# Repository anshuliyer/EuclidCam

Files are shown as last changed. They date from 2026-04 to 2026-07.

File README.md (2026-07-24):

# EuclidCam

Custom embedded camera firmware for a Raspberry Pi point-and-shoot. Runs headlessly on a 480×320 SPI display with a capacitive touch panel.

```
euclidcam/
├── firmware/python/       # On-device firmware runtime engine
│   ├── main.py            # Main entry point and orchestration loop
│   ├── filters/           # Custom PIL photo filters (Glam, 35mm, Summer, etc.)
│   ├── UI/                # Display renderer, touch digitizer driver, and themes
│   ├── settings/          # Viewfinder composition grids (3x3, Golden Ratio)
│   ├── connectivity/      # Flask remote control server & Wi-Fi configuration
│   └── IO/                # Hardware GPIO flash & battery management
├── docs/                  # Technical documentation & hardware reference manual
├── scripts/               # Bootstrapping & asset utility scripts
├── assets/                # Core visual media, logos, and typography fonts
├── tests/                 # Firmware test suite
├── Makefile               # Installation, deployment, and service targets
├── requirements.txt       # Python dependencies
└── LICENSE                # GNU Affero General Public License v3.0 (AGPLv3)
```

*(Note: The `Captured/` photo directory is automatically created dynamically on first start by the firmware engine).*

## Setup

This software is production-ready and shippable. Hardware dependencies (`picamera2`) are assumed to be available via the Raspberry Pi OS `apt` repositories. Python dependencies are strictly pinned.

```bash
make install          # installs apt dependencies and pip requirements.txt
make run              # foreground launch
make service-install  # register systemd unit
```

## Dev

```bash
make check   # syntax-check all .py files
make lint    # flake8
make clean   # remove __pycache__, temp.jpg
```

## License
This project is licensed under the **GNU Affero General Public License v3.0 (AGPLv3)** — see the [LICENSE](LICENSE) file for details.

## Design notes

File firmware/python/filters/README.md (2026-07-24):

# filters/

Each file exposes one function: `apply_<name>_filter(pil_img) -> Image`.  
`FilterMode` in `main.py` discovers it automatically by name convention.

| Module | Name | Look |
|---|---|---|
| `glam.py` | Glam | High-contrast B&W, soft gaussian glow |
| `nineties.py` | '90s | Lifted matte blacks, punchy contrast, 90s print|
| `film35mm.py` | 35mm | Point-and-shoot flash, lifted blue shadows |
| `indoor.py` | Indoor | Warm shadows, low contrast, indoor flash feel |
| `italian_summer.py` | Summer | Vivid Mediterranean warmth |
| `uni.py` | UnI | Vintage warm tint, lifted shadows |
| `nostalgia.py` | Nostalgia | Faded, desaturated retro |
| `low_light.py` | — | Used by `LowLightMode`, not in filter menu |

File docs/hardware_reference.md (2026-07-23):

# EuclidCam Core Reference
This document outlines the core dependencies, execution commands, and hardware initialization steps for the EuclidCam firmware. You can use this as a reference for integrating the camera engine and touch UI into other SDK projects.

## Fresh OS Setup (From Scratch)

If you are starting from a completely blank, freshly flashed Raspberry Pi OS memory card, run these exact shell commands in order over SSH or a connected keyboard:

```bash
# 1. Update the system package lists
sudo apt-get update -y
sudo apt-get upgrade -y

# 2. Enable SPI and I2C interfaces (Required for Display and Hardware Sensors)
sudo raspi-config nonint do_spi 0
sudo raspi-config nonint do_i2c 0

# 3. Clone the EuclidCam repository
git clone https://github.com/anshuliyer/EuclidCam.git
cd EuclidCam

# 4. Install all hardware and python dependencies via the Makefile
make install

# 5. Enable the EuclidCam systemd service to start automatically on boot
make service-install

# 6. Reboot the system to apply SPI/I2C changes and start the camera!
sudo reboot
```

## Hardware Wiring Guide

To ensure the firmware seamlessly communicates with the hardware, follow this pinout configuration.

### 1. ILI9341 Display (SPI)
- **MOSI / MISO / SCLK:** Standard Raspberry Pi SPI0 pins (GPIO 10, 9, 11)
- **CS (Chip Select):** GPIO 8 (CE0)
- **DC (Data/Command):** GPIO 24
- **RST (Reset):** GPIO 25
- **BL (Backlight):** Connect to 3.3V or 5V (depending on your module)

### 2. XPT2046 Touch Digitizer (SPI)
The touch controller shares the same SPI bus as the display, but uses a different Chip Select pin.
- **MOSI / MISO / SCLK:** Share with the Display
- **CS (Chip Select):** GPIO 7 (CE1)
- **IRQ (Pen Interrupt):** GPIO 17

### 3. Physical Shutter Button
- Wire a tactile button between **GPIO 21** and **GND**. The firmware uses an internal pull-up resistor, so it reads active-low when pressed.

### 4. Camera Module
- Connect a compatible camera module (e.g., Raspberry Pi Camera V2 or HQ Camera) via the CSI ribbon cable port. The libcamera backend will automatically detect the sensor type upon boot.
## Core Dependencies

To run the camera engine, display, and touch drivers, the following dependencies are required.

### 1. System Packages (APT)
On a Raspberry Pi, it is heavily recommended to install the hardware-linked Python packages via `apt` to avoid complex wheel compilation for the ARM architecture (especially for `numpy` and `picamera2`).
```bash
sudo apt-get update
sudo apt-get install -y python3-picamera2 python3-numpy python3-pil python3-flask python3-evdev python3-qrcode python3-requests python3-adafruit-blinka python3-adafruit-circuitpython-rgb-display libcap-dev libcamera-apps
```

### 2. Python Packages (PIP)
If you are setting up an isolated virtual environment, you can use `pip`:
```text
Pillow>=9.0.0
numpy>=1.21.0
Flask>=2.0.0
qrcode>=7.0
adafruit-circuitpython-rgb-display>=3.0.0
Adafruit-Blinka>=8.0.0
evdev>=1.6.0
```

---

## Execution Commands

### Running the Camera (Standard Mode)
Boots the camera engine, rendering the UI and camera feed directly to the ILI9341 SPI display.
```bash
# Using the Makefile wrapper:
make run

# Running directly from the Python layer:
cd firmware/python
python3 main.py
```

### Running the Camera (Benchmark Mode)
Boots the camera engine while drawing a live uptime timer to the screen. It also spawns a background daemon thread that queries the Raspberry Pi's `vcgencmd get_throttled` state every 60 seconds and logs the results to a local CSV file to test battery life.
```bash
# Using the Makefile wrapper:
make benchmark

# Running directly from the Python layer:
cd firmware/python
python3 main.py --benchmark
```

---

## Touch Screen Integration

The touch interface utilizes the resistive touchscreen digitizer (typically an XPT2046 or ADS7846) over SPI. 

### 1. Touch digitizer logic
Because the graphical UI (Pillow) and the hardware display (`ili9341`) handle rotations differently, the raw coordinates from the touch digitizer must be mapped to the actual screen geometry.

**Hardware Driver:** `evdev` is used to capture `ABS_X` and `ABS_Y` touch events in `calibrate_touch.py`.
**Firmware Parsing:** In `touch_interface.py`, the firmware directly speaks to the SPI hardware bus at `1MHz` to bypass OS-level touch noise and read stable ADC voltages.

### 2. Touch Calibration
Before the UI can accurately determine button presses, the raw touch digitizer bounds must be mapped. 
Run the following interactive calibration script and tap the four corners of the screen when prompted:
```bash
cd firmware/python
python3 calibrate_touch.py
```
This generates a `touch_settings.json` file containing the `x_min`, `x_max`, `y_min`, and `y_max` mappings used by the UI engine.

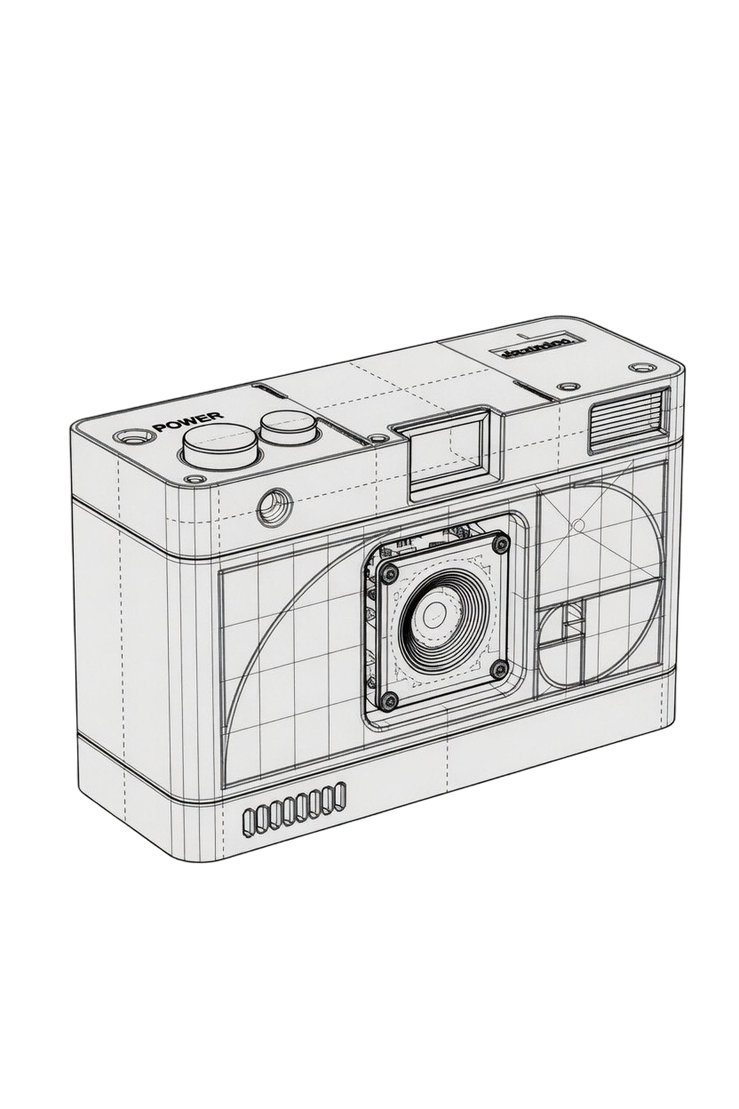
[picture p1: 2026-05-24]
assets/camera_blueprint.png

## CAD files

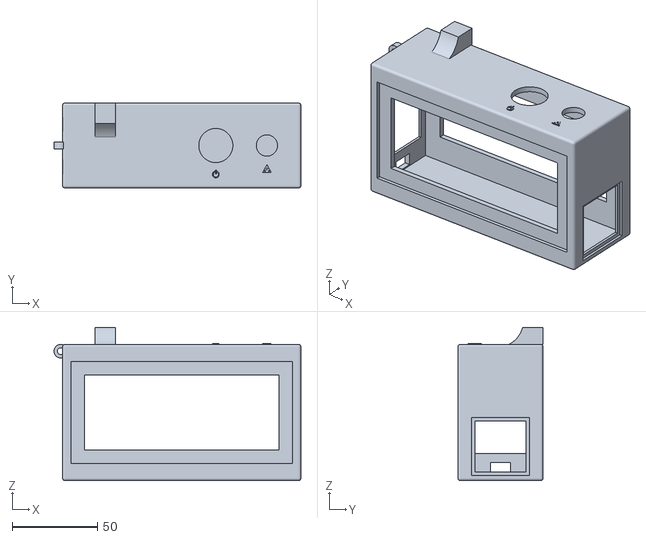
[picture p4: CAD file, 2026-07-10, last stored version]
Webapp/exports/main_chassis.stl
145.0 x 50.0 x 90.0

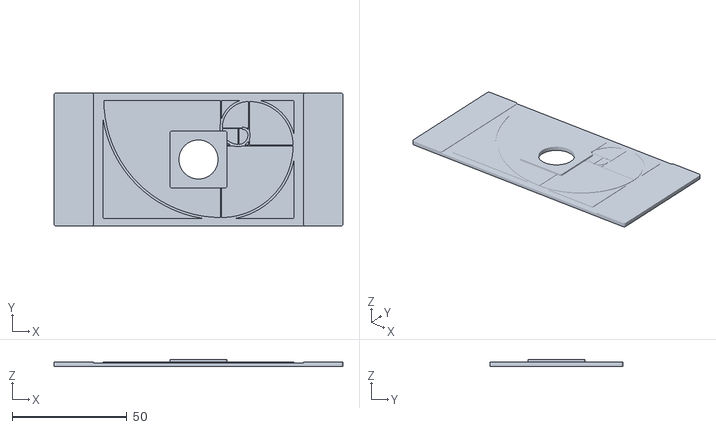
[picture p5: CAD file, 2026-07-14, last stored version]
Webapp/exports/front_plate.stl
126.0 x 58.0 x 3.00

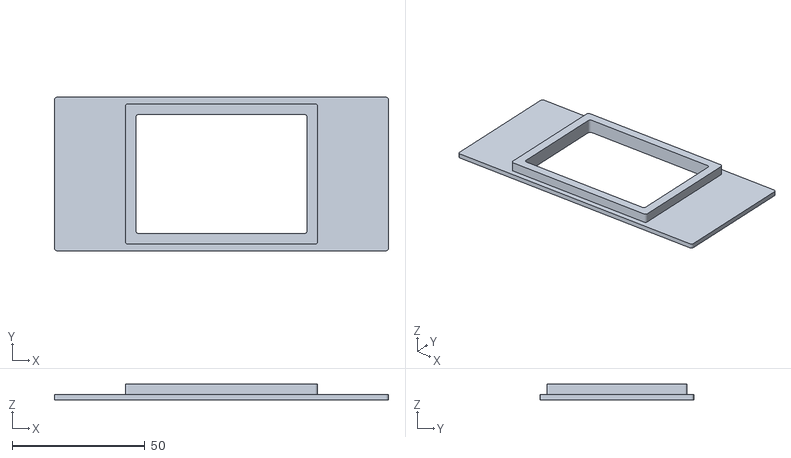
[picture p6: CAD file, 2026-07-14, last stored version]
Webapp/exports/back_plate.stl
126.0 x 58.0 x 6.00

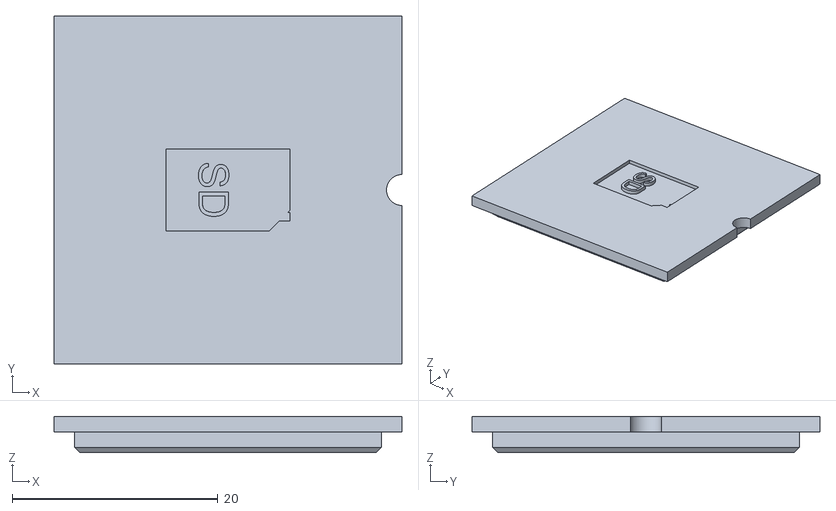
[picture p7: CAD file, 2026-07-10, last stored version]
Webapp/exports/sd_door.stl
33.8 x 33.8 x 3.50

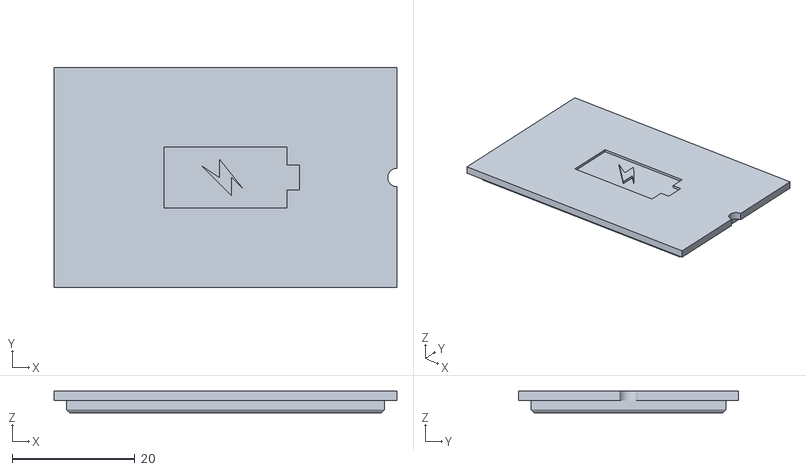
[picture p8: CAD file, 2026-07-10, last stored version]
Webapp/exports/battery_door.stl
55.8 x 35.8 x 3.50

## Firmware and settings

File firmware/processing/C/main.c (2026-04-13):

#define STB_IMAGE_IMPLEMENTATION
#include "stb_image.h"
#define STB_IMAGE_WRITE_IMPLEMENTATION
#include "stb_image_write.h"

#include <stdio.h>
#include <stdlib.h>

/**
 * PiDigiCam: Minimal C Image Enhancer for ARMv6
 * 
 * This entry point is designed for debian-based ARMv6 microcontrollers.
 * It uses the 'stb' single-header libraries for zero-dependency image I/O.
 */

// Simple Bilinear Upscaling (Baseline Enhancement)
void upscale_x2(unsigned char* src, int sw, int sh, unsigned char* dst) {
    int dw = sw * 2;
    int dh = sh * 2;
    for (int y = 0; y < dh; y++) {
        for (int x = 0; x < dw; x++) {
            float gx = (float)x / 2.0f;
            float gy = (float)y / 2.0f;
            int gxi = (int)gx;
            int gyi = (int)gy;
            
            // Simple nearest/bilinear mix for performance on ARMv6
            dst[y * dw + x] = src[gyi * sw + gxi];
        }
    }
}

int main(int argc, char** argv) {
    if (argc < 3) {
        fprintf(stderr, "Usage: %s <input.jpg> <output.png>\n", argv[0]);
        return 1;
    }

    const char* input_path = argv[1];
    const char* output_path = argv[2];

    int width, height, channels;
    printf("Loading image: %s\n", input_path);
    unsigned char* img = stbi_load(input_path, &width, &height, &channels, 0);
    
    if (!img) {
        fprintf(stderr, "Error: Could not load image %s\n", input_path);
        return 1;
    }

    printf("Image Loaded: %dx%d, %d channels\n", width, height, channels);
    
    int out_w = width * 2;
    int out_h = height * 2;
    unsigned char* out_img = (unsigned char*)malloc(out_w * out_h * channels);

    if (!out_img) {
        fprintf(stderr, "Error: Out of memory\n");
        stbi_image_free(img);
        return 1;
    }

    printf("Enhancing image to %dx%d...\n", out_w, out_h);
    
    // Process each channel
    for (int c = 0; c < channels; c++) {
        unsigned char* src_c = (unsigned char*)malloc(width * height);
        unsigned char* dst_c = (unsigned char*)malloc(out_w * out_h);
        
        // Extract channel
        for (int i = 0; i < width * height; i++) src_c[i] = img[i * channels + c];
        
        upscale_x2(src_c, width, height, dst_c);
        
        // Insert channel back
        for (int i = 0; i < out_w * out_h; i++) out_img[i * channels + c] = dst_c[i];
        
        free(src_c);
        free(dst_c);
    }

    printf("Writing output: %s\n", output_path);
    if (!stbi_write_png(output_path, out_w, out_h, channels, out_img, out_w * channels)) {
        fprintf(stderr, "Error: Could not save image %s\n", output_path);
    } else {
        printf("Successfully enhanced image!\n");
    }

    stbi_image_free(img);
    free(out_img);

    return 0;
}

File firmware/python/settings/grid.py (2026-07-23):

import numpy as np
from PIL import Image, ImageDraw

class CompositionGrid:
    """
    Handles drawing compositional grids (3x3, Golden Ratio/Euclid) on PIL images.
    """
    OFF = "OFF"
    GRID_3x3 = "3x3"
    EUCLID = "Euclid"

    def __init__(self, color=(220, 220, 200), width=2):
        self.color = color
        self.width = width

    def apply(self, pil_img, mode):
        """
        Applies the selected grid mode to the PIL image.
        """
        if mode == self.OFF or not mode:
            return pil_img
        
        draw = ImageDraw.Draw(pil_img)
        w, h = pil_img.size

        if mode == self.GRID_3x3:
            # Rule of Thirds
            # Vertical
            draw.line([(w // 3, 0), (w // 3, h)], fill=self.color, width=self.width)
            draw.line([(2 * w // 3, 0), (2 * w // 3, h)], fill=self.color, width=self.width)
            # Horizontal
            draw.line([(0, h // 3), (w, h // 3)], fill=self.color, width=self.width)
            draw.line([(0, 2 * h // 3), (w, 2 * h // 3)], fill=self.color, width=self.width)
        
        elif mode == self.EUCLID:
            # True Golden Spiral (Fibonacci recursive squares and arcs)
            phi = 1.61803398875
            
            # Center a perfect Golden Rectangle in the screen
            if w / h > phi:
                # Screen is wider than GR, center horizontally
                gr_h = h
                gr_w = int(h * phi)
                x0 = (w - gr_w) // 2
                y0 = 0
            else:
                # Screen is taller than GR, center vertically
                gr_w = w
                gr_h = int(w / phi)
                x0 = 0
                y0 = (h - gr_h) // 2

            rx, ry, rw, rh = x0, y0, gr_w, gr_h
            
            # Direction of the cut: 0: right, 1: top, 2: left, 3: bottom
            direction = 0
            for i in range(8): # 8 iterations is visually perfect
                if rw < 2 or rh < 2: break
                
                sq = min(rw, rh)
                
                if direction == 0: # Right
                    sx, sy = rx + rw - sq, ry
                    rw -= sq
                    cx, cy = sx, sy + sq
                    start, end = 270, 360
                elif direction == 1: # Top
                    sx, sy = rx, ry
                    ry += sq
                    rh -= sq
                    cx, cy = sx + sq, sy + sq
                    start, end = 180, 270
                elif direction == 2: # Left
                    sx, sy = rx, ry
                    rx += sq
                    rw -= sq
                    cx, cy = sx + sq, sy
                    start, end = 90, 180
                else: # Bottom
                    sx, sy = rx, ry + rh - sq
                    rh -= sq
                    cx, cy = sx, sy
                    start, end = 0, 90
                    
                # Draw the bounding square
                draw.rectangle([sx, sy, sx + sq, sy + sq], outline=self.color, width=self.width)
                
                # Draw the golden arc
                draw.arc([cx - sq, cy - sq, cx + sq, cy + sq], start, end, fill=self.color, width=max(1, self.width))
                
                direction = (direction + 1) % 4
                
        return pil_img

if __name__ == "__main__":
    # Simple standalone verification (Mocks FB/Camera if needed, but here just testing PIL)
    print("CompositionGrid Class test...")
    test_img = Image.new('RGB', (480, 320), color=(255, 255, 255))
    grid = CompositionGrid()
    
    # Test Euclid
    res = grid.apply(test_img.copy(), CompositionGrid.EUCLID)
    res.save("test_euclid.png")
    print("Saved test_euclid.png")
    
    # Test 3x3
    res = grid.apply(test_img.copy(), CompositionGrid.GRID_3x3)
    res.save("test_3x3.png")
    print("Saved test_3x3.png")

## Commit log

2026-04-13 [PCD] kodak 35mm filter added
2026-04-14 [prebuilts] Update enhance prebuilt for Raspberry Pi Zero W (ARMv6)
2026-04-23 [ECD] Placing mounted system
2026-04-23 [ECD] Filter interfaces
2026-04-23 Cross button
2026-04-23 [FIX] obsolete qr_scanner import
    [main.py]
2026-04-23 added device storage status to web ui
2026-04-25 [TOUCH] Fixed axis swapping logic in touch interface
    [touch_interface.py]
2026-04-25 [ECD] Replaced vertical list menu with a robust horizontal grid layout for better touch performance
    [touch_interface.py]
2026-04-25 [ECD] Optimization: Increased FPS and tuned camera clarity/contrast
2026-04-26 Revert "[ECD] Optimization: Optimized framebuffer write speed to reduce tearing"
    This reverts commit c0d1807daac61a9c9b0022805cc1ead2708e2685.
    [main.py]
2026-04-26 Revert "[ECD] Optimization: Increased FPS and tuned camera clarity/contrast"
    This reverts commit f297dd2e82d9a20c8d9719d5d314c7c6518bad98.
    [main.py]
2026-04-26 [ECD] Added dedicated Low Light mode with hardware noise reduction and preview boosting
    [main.py, touch_interface.py]
2026-04-26 [ECD] Modularized Low Light logic into filters directory
2026-04-26 [ECD] Improved touch isolation by increasing button margins and reducing impact area
2026-04-26 [ECD] Premium UI Redesign: Implemented card-based grid with custom iconography and glassmorphism
    [touch_interface.py]
2026-04-26 [ECD] Refactored touch logic to Layered Mapping system: fixed corner selection bug
    [touch_interface.py]
2026-04-26 [ECD] Redesigned capture logo to use geometric triangle (removed cross look)
    [main.py]
2026-04-26 [ECD] UI Refactor: Translucent glass buttons in settings menu & expanded QR close hitbox
2026-04-26 [ECD] Made QR close button visually massive and easily tappable
2026-04-26 [ECD] Standardized massive cross button across all menus & fixed QR code touch fallthrough bug
    [touch_interface.py]
2026-04-26 [ECD] Replaced Cyberpunk filter with UnI vintage film aesthetic
    [main.py, uni.py]
2026-04-26 [ECD] Replaced Kodak filter with gritty 35mm point-and-shoot flash aesthetic
    [film35mm.py, main.py]
2026-04-26 [ECD] Forced camera capture to match preview FOV by using 1080p cropped sensor mode
2026-04-26 [ECD] Replaced Bokeh filter with Indoor filter (warm, lifted shadows aesthetic)
    [indoor.py, main.py]
2026-04-26 [ECD] Reverted hardware zoom config; implemented slight 1.05x digital crop for saving
    [main.py]
2026-04-26 [ECD] Updated zoom to 1.6x (Standard lens equivalent) and unified preview/capture cropping
2026-04-26 [ECD] Fixed gallery access: added missing GALLERY command handler to InputHandler
    [main.py]
2026-04-26 [ECD] Re-styled Gallery UI to match Settings: unified header, glassmorphism cards, and standard cross button
2026-04-27 [UI] Implement 180-degree orientation flip and settings persistence
    [main.py, touch_interface.py]
2026-04-27 [UI] Centralize orientation rotation in display helper and fix capture screens
    [main.py]
2026-04-27 [GPIO] Implement physical flash logic on pin 21 and refactor IO module
2026-04-27 [GPIO] Configure GPIO 26 as virtual ground for flash circuit
2026-04-27 Add Disco filter with heavy processing effects
2026-06-09 [TEMP] ili9341 camera
2026-06-09 Switch to apt dependencies instead of pip
2026-06-09 [TEMP] display color fix
    [main.py]
2026-06-09 [TEMP] fix resize logic
    [main.py]
2026-06-09 [TEMP] fix red/blue color swap
    [main.py]
2026-06-09 [TEMP] Add shutter button to GPIO21
2026-06-09 [TEMP] Switch flash to GPIO16 and remove screen flash
2026-06-10 [TEST] add touch calibration script
2026-06-10 [TEMP] Add calibrated touch settings
2026-06-10 [TEMP] Rewrite TouchInterface to pure Python SPI
2026-06-11 [TEST] Update touch calibration script to show mapped outputs
2026-06-11 [TEST] Polling calibration script
2026-06-11 [TEST] Add smart 3-point interactive calibration
2026-06-11 [TEST] Add cal.py interactive calibration script
2026-06-11 Implement fat-finger rejection algorithm
2026-06-11 Fix gallery morphing and make menu buttons taller
2026-06-11 Implement Bluetooth transfer UI and background framework
2026-06-12 Fix nmcli hotspot blocking the UI main loop
    [main.py]
2026-06-12 Print Live QR generation exception to screen
2026-06-12 Remove gallery image filter and use correct native Dark Mode logo
2026-06-12 Increase vibrancy of Charcoal/Beige theme for camera LCD
2026-06-12 Fuse logo animation with golden ratio dotted explosion
2026-06-12 Revert to dotted explosion boot animation and fix text visibility
    [main.py]
2026-06-12 Enhance explosion animation with premium kinematics and volumetric depth
2026-06-12 Thread boot animation for zero-latency startup and update Euclid grid to true Golden Spiral overlay
2026-06-12 Fix RGB/BGR color swap bug affecting post-capture preview and gallery
    [main.py]
2026-06-12 Boost touch sensitivity by restructuring ADC reads for RC settling and relaxing noise thresholds
    [touch_interface.py]
2026-06-12 Massively optimize gallery rendering with frame caching and libjpeg thumbnailing to restore UI framerate and touch response
2026-06-12 Fix gallery visual burn-in and correct arrow hitboxes
    [main.py, touch_interface.py]
2026-06-12 Remove test assets, old summaries, sample files, and 50MB virtual drive
2026-06-12 Fix AttributeError state -> config in battery UI
2026-06-12 Fill battery icon solidly when power is healthy
2026-06-12 Add battery benchmark shell script
2026-06-12 SDK: Add fast C binary and Python utility for zero-dependency SPI boot splash screen
2026-06-12 SDK: Lower SPI baudrate to 24MHz to fix ILI9341 artifacting
2026-06-12 SDK: Fix SPI chunk termination by manually controlling CS
2026-06-12 SDK: Fix SPI timing distortion by grouping ioctls and preserving GPIO file descriptors
2026-06-12 SDK: Lower SPI clock to 10MHz to improve signal integrity over breadboard
2026-06-12 Benchmarking: Add total cumulative battery time calculation
2026-06-12 SDK: Add python fallback script to draw splash screen using adafruit drivers
2026-07-10 feat(webapp): integrate and style 3D Design viewer, update dark mode boot styling
    [back_plate.stl, battery_door.stl, front_plate.stl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]
2026-07-14 [UI] New design
    [back_plate.stl, front_plate.stl]
2026-07-20 [FIX] Touch calibration bounds
2026-07-20 [ENHANCEMENT] 4-point calibration
2026-07-20 [EXPERIMENT] Single-button navigation
2026-07-21 [UI] Bulletproof single-button UI with circular carousel
2026-07-23 [UI] Shorten shutter hold window to 0.25s and display Flash toggle state in main menu
    [main.py]
2026-07-23 [UI] Increase single button click sensitivity window and add smooth menu hold repeat
2026-07-23 [CONNECT] Add gear icon and modal to configure board WiFi from web UI
2026-07-23 [UI] Remove cross sign button and update instructions on QR connection view
2026-07-23 [FIX] Resolve AttributeError by changing self.modes to self._modes in InputHandler
    [main.py]
2026-07-23 [UI] Make Wi-Fi icon dynamic (shows EC badge in Connect mode, Wi-Fi arcs on active network, resets when offline)
    [main.py]
2026-07-23 [WEBAPP] Add Remote mode tab with live MJPEG stream, shutter capture button, and mode selection grid
2026-07-23 [FIX] Resolve live stream file contention with atomic os.replace, fix remote capture via ENTER command, and populate filter modes
    [main.py]
2026-07-23 [FIX] Make Connect startup non-blocking in background daemon thread to prevent systemd watchdog process reset
    [main.py]
2026-07-23 [FIX] Resolve AttributeError in remote grid setup by using CompositionGrid.GRID_3x3 and CompositionGrid.EUCLID
    [main.py]
2026-07-23 [FIX] Update CompositionGrid default color (220, 220, 200) and width (2) so remote web app grid selection renders crisp bright grid lines
    [grid.py]
2026-07-23 [FILTERS] Remove Disco mode filter from mode registry, web app UI, and server status
2026-07-23 [FILTERS] Remove disco.py filter file
2026-07-23 [WEBAPP] Add Shutter Timer scroller (0s to 20s in 5s increments) with live countdown
2026-07-23 [HARDWARE] Blip physical flash LED each second during the last 5 seconds of shutter timer
2026-07-23 [FIX] Dispatch remote capture request immediately to camera on shutter press so physical flash LED blips right away in last 5s
2026-07-23 [FIX] Restore full timer duration countdown and blip physical flash LED once per second in the last 5 seconds
    [main.py]
2026-07-23 refactor: move webapp to dedicated EuclidCamWebapp repo
    [back_plate.stl, battery_door.stl, front_plate.stl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]
2026-07-24 feat(filter): add '90s vintage film filter based on reference specs
2026-07-25 fix(imports): import ImageEnhance from PIL in main.py
    [main.py]
2026-07-25 fix(anti-flicker): enable AeFlickerMode auto anti-banding by default across preview and captures; keep Exposure configurable
    [main.py]
2026-07-25 fix(camera): enable IMX708 PDAF autofocus (AfMode: 2), centre-weighted subject metering (AeMeteringMode: 0), 100Hz anti-flicker (AeFlickerMode: 2 + AeFlickerPeriod: 10000), and remove static Analogue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
    [main.py]
2026-07-25 fix(preview): remove redundant BGR channel swap to restore true RGB colors in live preview
    [main.py]
2026-07-25 fix(camera): use valid AeFlickerMode 1 + AeFlickerPeriod 10000 for RPi IPA, and convert BGR -> RGB for display
    [main.py]
2026-07-25 fix(nineties): skip heavy UnsharpMask during live preview stream to maintain high FPS and responsive UI
    [main.py]
2026-07-25 feat(filters): add Cinematic Bokeh filter module with radial depth-of-field masking & specular aperture discs
2026-07-25 perf(bokeh): optimize bokeh filter using multi-scale pyramidal downsampling for <0.2s capture processing
2026-07-25 fix(hud): sync active_mode_name dynamically in _render so top HUD badge reflects active mode
    [main.py]
2026-07-26 perf(engine): eliminate preview PIL/NumPy conversion churn and upgrade all filter modules to C-level LUT tables
